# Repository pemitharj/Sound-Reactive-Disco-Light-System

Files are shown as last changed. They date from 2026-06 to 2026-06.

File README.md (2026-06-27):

# Sound Reactive Disco Light System

An analog electronics project that converts real-time audio signals into dynamic LED lighting effects.

---

## Abstract
The Sound Reactive Light System is an analog electronics project designed to produce dynamic lighting effects that respond directly to audio input. The system analyzes different frequency bands of background music and drives LEDs in real time to create interactive visual effects for events and entertainment environments.

---

## Features
- Real-time audio-responsive lighting
- Frequency band separation (Bass, Mid, Treble)
- Analog signal processing (no microcontroller)
- Envelope detection and amplification
- LED visualization based on sound intensity

---

## System Overview
The system captures audio signals, amplifies them, and separates them into three frequency bands using analog filters. Each band is processed independently to drive LED outputs based on signal intensity.

---

## Technologies Used
- Analog Electronics
- Active Filters (Low-pass, Band-pass, High-pass)
- Operational Amplifiers
- PCB Design
- LTspice Simulation
- SolidWorks (Enclosure Design)

---

## Results
The system successfully produces real-time LED responses synchronized with music across bass, mid, and treble frequency ranges.

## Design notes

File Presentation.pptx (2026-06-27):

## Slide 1

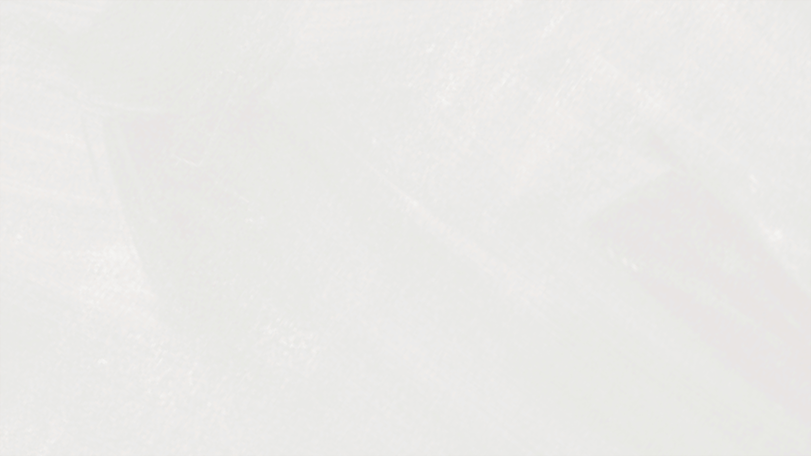
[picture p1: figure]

VoltEdge

SOUND REACTIVE DISCO LIGHT BOX

Samarasekara S.M.R.P. 230564L
Jayakody J.A.C.P. 230268H Kaushalya R.G.S.P. 230327N Jayasinghe J.A.P.R. 230280L

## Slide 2

The Sound Reactive Light System is an analog electronic project designed to create dynamic lighting effects that respond directly to audio signals.
By analyzing different frequency bands of background music, the system drives a set of LEDs to change patterns in real time, enhancing the ambiance and visual appeal at parties or events.
Using analog circuits such as band-pass filters, amplifiers and a regulator, the design processes sound frequencies will cove the concepts in signal processing and circuit design while delivering an engaging interactive experience.

Introduction

3

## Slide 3

1. Sound Capture and Amplification
  - Music is captured via a “Electret Microphone”
  - Preamplification and amplification using “NE5532P , LM358N” OpAmp ICs
  - x11 times amplification

Methodology

3

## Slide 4

2. Frequency band seperation

1. Low Pass Active Filter
  - “NE5532P” OpAmp 2nd order filtering
  - 267Hz cutoff
2.Bandpass
  - “NE5532P” OpAmp 2nd order filtering
  - 328Hz and 2411Hz cutoff
3. Highpass Active Filter
  - “NE5532P” OpAmp 2nd order fltering
  - 3386Hz cutoff

3

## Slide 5

4.Amplification and Driving LEDs

  - All the three bands are amplified and used for LED driving
  - Low Pass by x7.8
  - Bandpass by x11
  - High pass by x11

3

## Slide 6

1. 9V battery will be used as power source
  - LT1086 - 5V model with 10uF capacitances
  - MAX1044 switched capacitor convertor or
a voltage divider circuit.

3.Power Supply

3

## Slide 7

Functionality

MICROPHONE

AMPLIFIER

FREQUENCY FILTERS

LED ARRAYS

LED DRIVE
AMPLIFIER

3

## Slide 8

PCB design

The pcb was created to organize the entire circuit in a clean compact and relaible way.

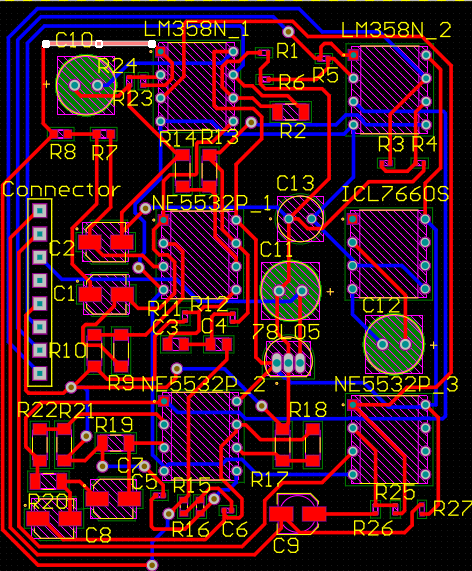
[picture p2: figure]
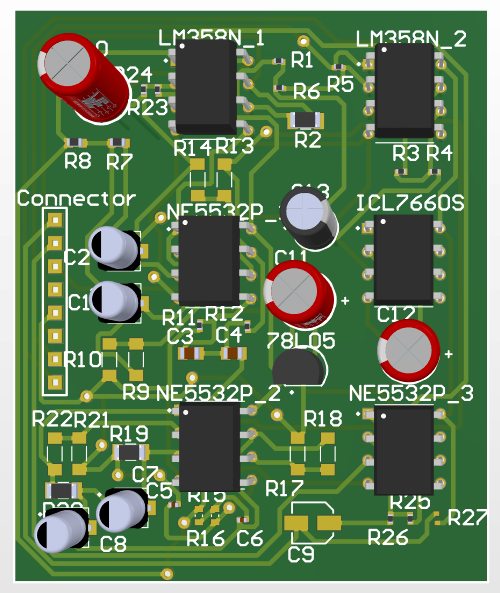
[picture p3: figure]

3

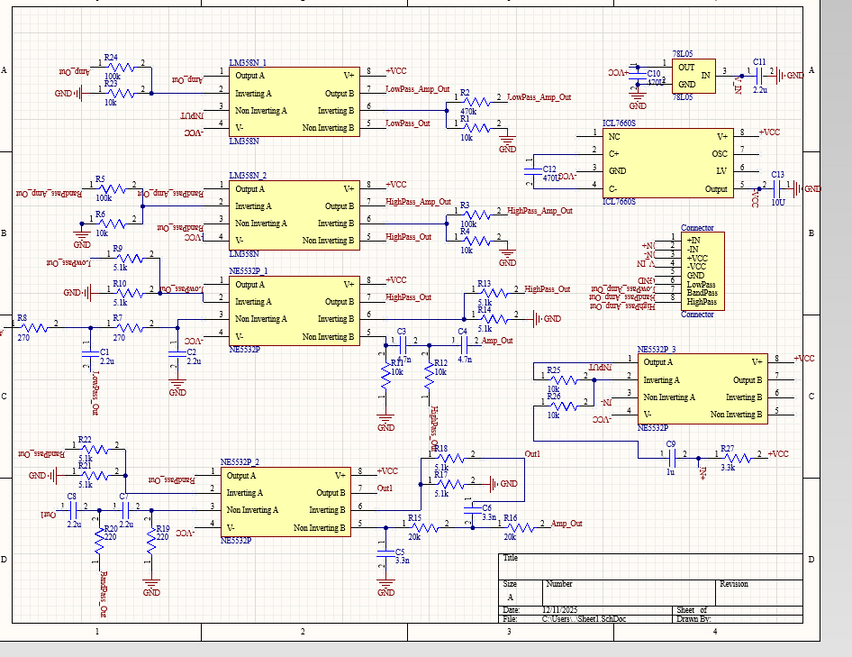
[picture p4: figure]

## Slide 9

PCB design

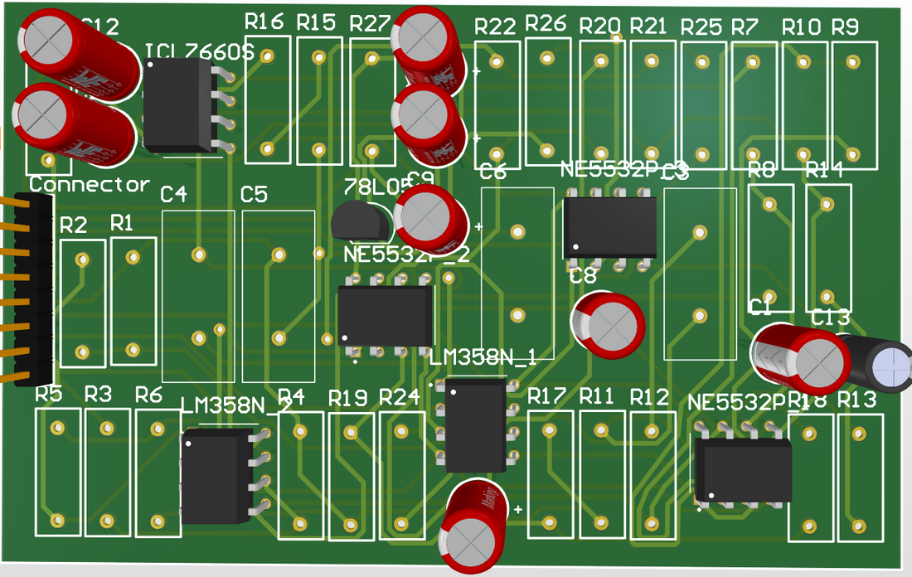
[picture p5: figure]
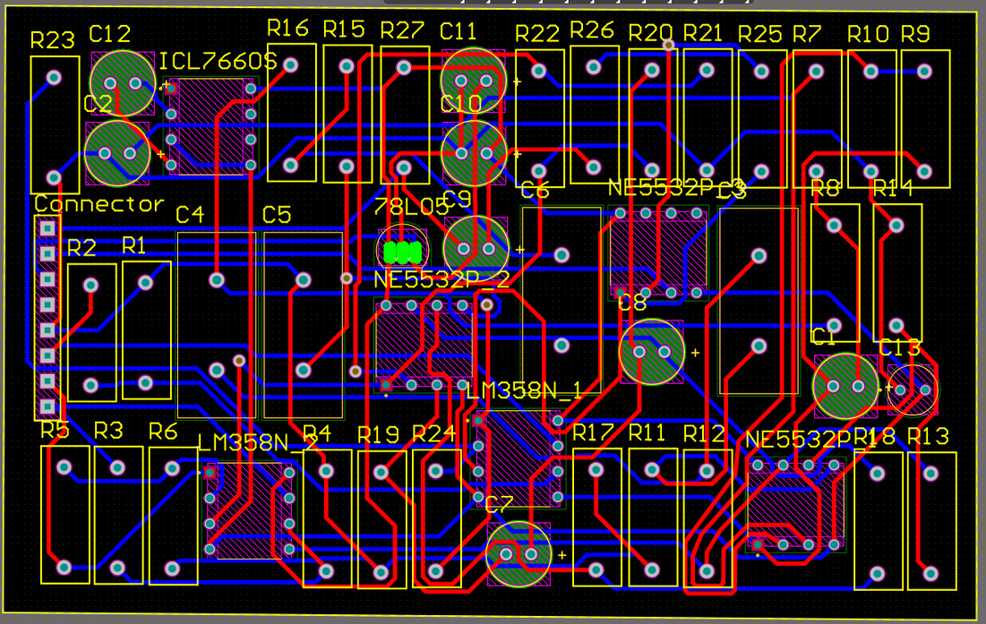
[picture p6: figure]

3

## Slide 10

PCB design

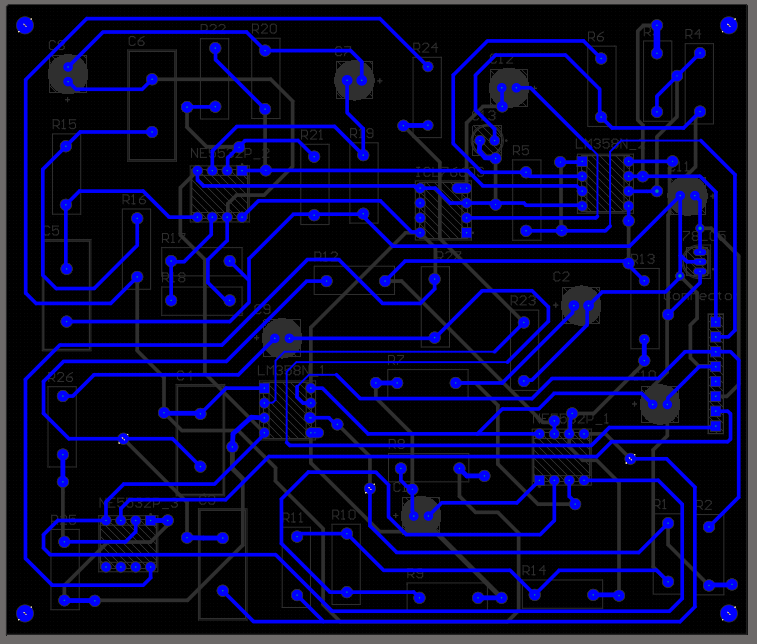
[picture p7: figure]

3

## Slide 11

Enclosure design

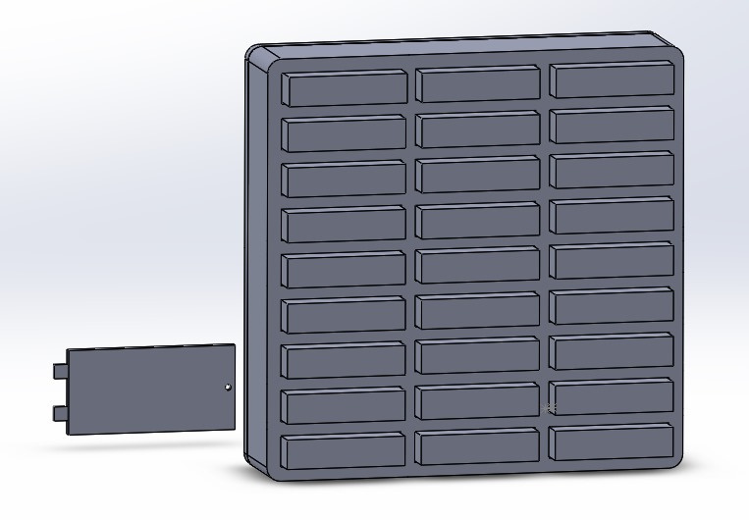
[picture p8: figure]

Enhances the aesthetics of the light box making it suitable for display during events or as part of the room

To protect the circuitry while giving the project a clean, professional appearence.

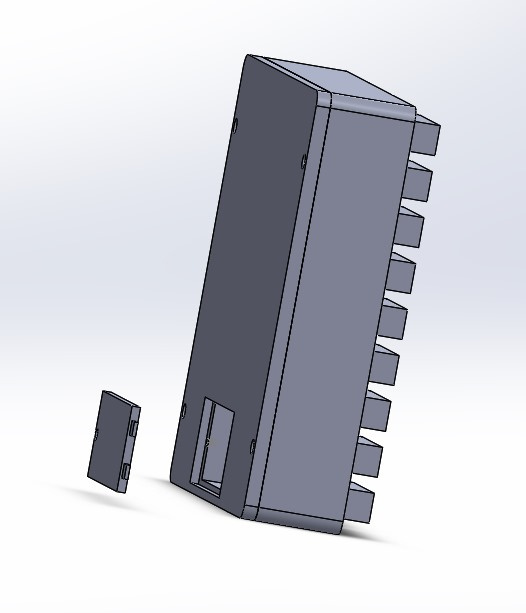
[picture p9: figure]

3

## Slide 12

Task Allocation

3

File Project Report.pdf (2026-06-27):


Department of Electronic & Telecommunication Engineering, University of Moratuwa, Sri Lanka.

# Sound Reactive Disco Light Box

Group Members:

230564L | Samarasekara S.M.R.P.
230268H | Jayakody J.A.C.P.
230327N | Kaushalya R.G.S.P.
230280L | Jayasinghe J.A.P.R

Submitted in partial fulfillment of the requirements for the module EN 2091 Laboratory Practice and Projects

2025.12.06

Sound Reactive Disco Light Box | Group No 29

Abstract

The Sound Reactive Light System is an analog electronics project designed to produce dynamic lighting effects that respond directly to audio input. By analyzing multiple frequency bands of background music, the system drives LEDs to create real-time visual patterns that enhance ambiance at events or parties. The design employs key analog building blocks—including band-pass filters, envelope detectors, and comparators—to isolate and process specific sound frequencies. Through this approach, the project demonstrates essential concepts in signal processing and circuit design while delivering an engaging and interactive audio-visual experience.

1

## Contents

1 Introduction and Functionality | 3
2 System Architecture | 3
3 Component Selection | 4
4 PCB Design | 5
5 Enclosure Design | 6
6 Software Simulation and Hardware Testing | 6
7 Conclusion and Future Works | 8
8 Contribution of Group Memebers | 9
9 References | 9

2

## 1 Introduction and Functionality

The Sound Reactive Light System is an analog electronic project designed to create dynamic lighting effects that respond directly to audio signals. By analyzing different frequency bands of background music, the system drives a set of LEDs to change patterns in real time, enhancing the ambiance and visual appeal at parties or events. Using analog circuits such as low-pass,band-pass,high-pass filters,amplifiers, the design processes sound frequencies will cove the concepts in signal processing and circuit design while delivering an engaging interactive experience.

- System will capture sound and amplify in real time operation continuously.
- The audio signal is split into three main frequency bands: bass, midrange, and treble.
- All the three bands are amplified and used for LED driving.
- LEDs light up or change patterns based on the intensity and presence of sound in their respective frequency bands.

## 2 System Architecture

Functional Block Diagram

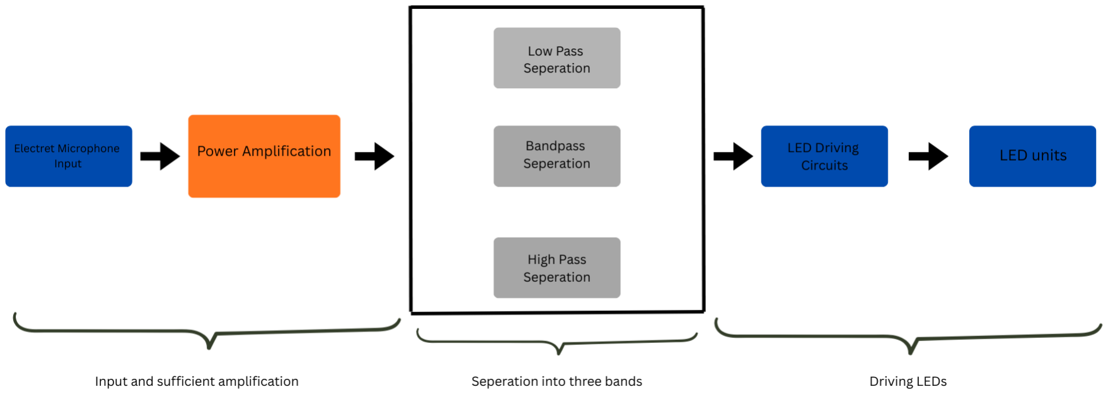
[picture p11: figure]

Figure 1: This is a full-width image.

1. Input
A Electret Condensor Microphoone is use to take the music inputs in to the system. And a DC blocking capcitor of value 1uF in series.
2. Power Amplification
A OpAmp amplification circuit is used to get the enough power amplification to the microphone signal in order to drive the rest of the circuit.
3. Three band seperation
The input audio signal is seperated into three bands of Lowpass, Bandpass and Highpass using Active OpAmp filters.
4. LED switching
Switching LEDs according to the output power of each filters.

3

## 3 Component Selection

### 3.1 Component justification

Component | Functionality | Reason
| Filtering
NE5532P OpAmp | Active filtering | Less distortion
LM358N OpAmp | Converts AC to DC | Less distortion
Power Supply
7805 voltage regulator | To provide +5v +VCC to opamps and LEDs | accuracy of about ±4%
ICL 7660S power invertor | Invert +5V to get -5V -VCC | Improves noise reduction
9V battery | Provide 9V DC power | availability and easy replacement
Input and Amplification
Condernsor microphone | Accepts music input signal | High sensitivity, compact size and low power requirements
NE5532P OpAmp | Amplifies input signal | Low noise of 15nV and less dis-tortion than other tested LM324 and TL072

Table 1: Circuit components categorized by functional sections

### 3.2 Cutoff frequency calculations

1. Low-Pass Filter Cutoff frequency:

f =

1
2πRC

=

1
2π · 270 · 2.2 · 10⁻⁶
= 267Hz
2. High-Pass Filter Cutoff frequency:

f =

1
2πRC

=

1
2π · 10 · 10³ · 4.7 · 10⁻⁹ = 3386Hz
3. Band-Pass Filter
(i) Low cutoff frequency:

f =

1
2πRC

=

1
2π · 220 · 2.2 · 10⁻⁶
328Hz

(ii) High cutoff frequency:

f =

1
2πRC

=

1
2π · 20 · 10³ · 3.3 · 10⁻⁹ = 2411Hz

4

## 4 PCB Design

The printed circuit board (PCB) for the Sound Reactive Light System was designed using Altium Designer, which enabled accurate schematic capture and efficient layout development. Surfacemount device (SMD) components were selected to achieve a compact and space-efficient design while reducing parasitic effects and improving signal integrity. A two-layer PCB was implemented to simplify routing, provide proper grounding, and minimize noise in sensitive analog signal paths. After completing all design rule checks (DRC) and final verification, the PCB was fabricated and assembled through JLCPCB, ensuring reliable manufacturing quality and dimensional accuracy.

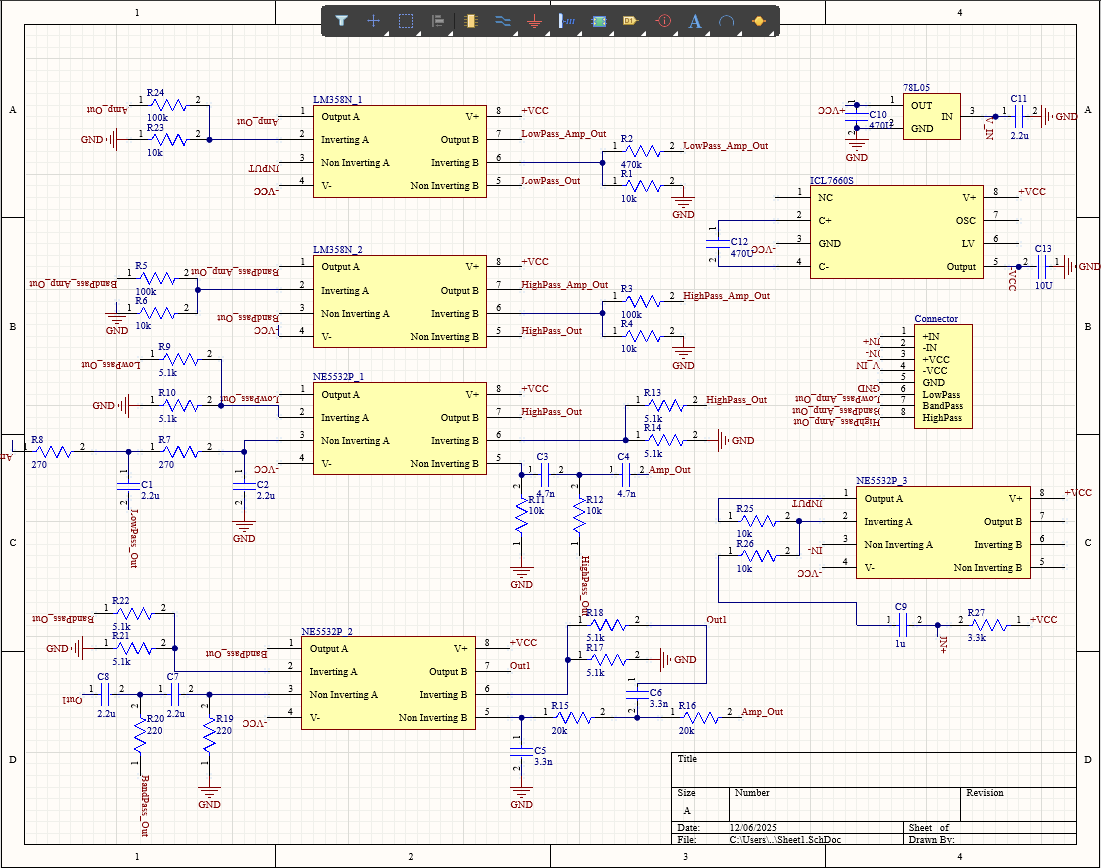
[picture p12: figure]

Figure 2: PCB Schematic

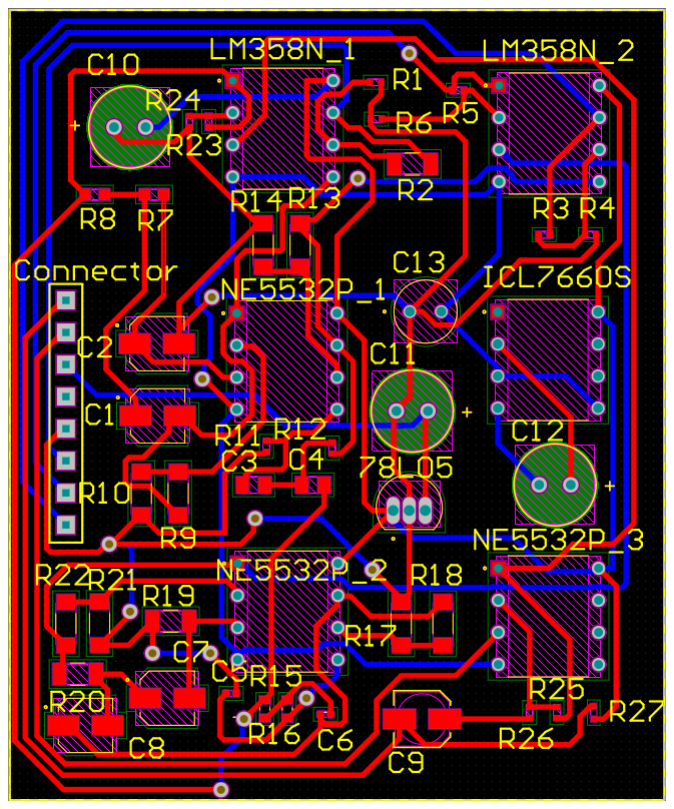
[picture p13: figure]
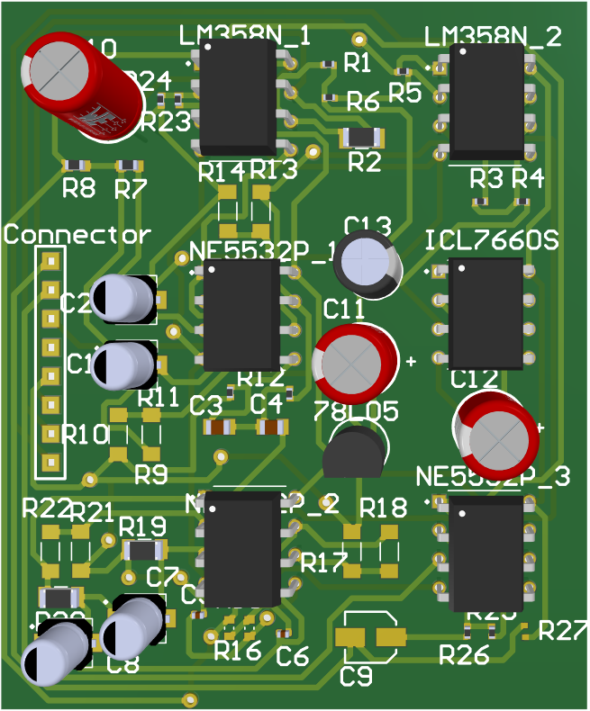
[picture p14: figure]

(a) 3D view PCB | (b) Routine of PCB

5

## 5 Enclosure Design

The enclosure for the Sound Reactive Light System was designed to provide a durable, safe, and visually appealing housing for the electronic circuitry and LED display. Its primary purpose is to protect internal components from physical damage, minimize electrical interference, and enhance the overall user experience by presenting a clean and organized final product.
The enclosure was constructed using PLA (polylactic acid), chosen for its strength, ease of fabrication, and cost-effectiveness. This material also offers good thermal stability and provides an aesthetically pleasing finish suitable for a display-oriented project.
The low thickness used in LED boxes allowed the LED effects to be visible while safeguarding the electronics inside.

Structural Layout
The internal layout was designed to ensure efficient use of space and proper separation of functional blocks. The PCB containing the band-pass filters, envelope detectors, and comparators was mounted securely using standoffs to prevent vibration and short circuits. The LED arrays were positioned along the front panel for maximum visibility, while wiring channels were created to keep signal lines organized and prevent noise coupling. A dedicated compartment was provided for the power supply to minimize interference with sensitive analog circuits.

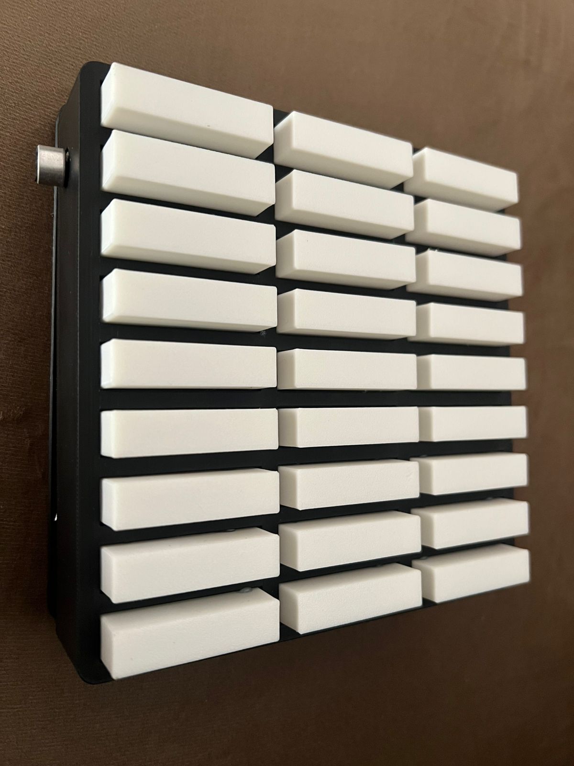
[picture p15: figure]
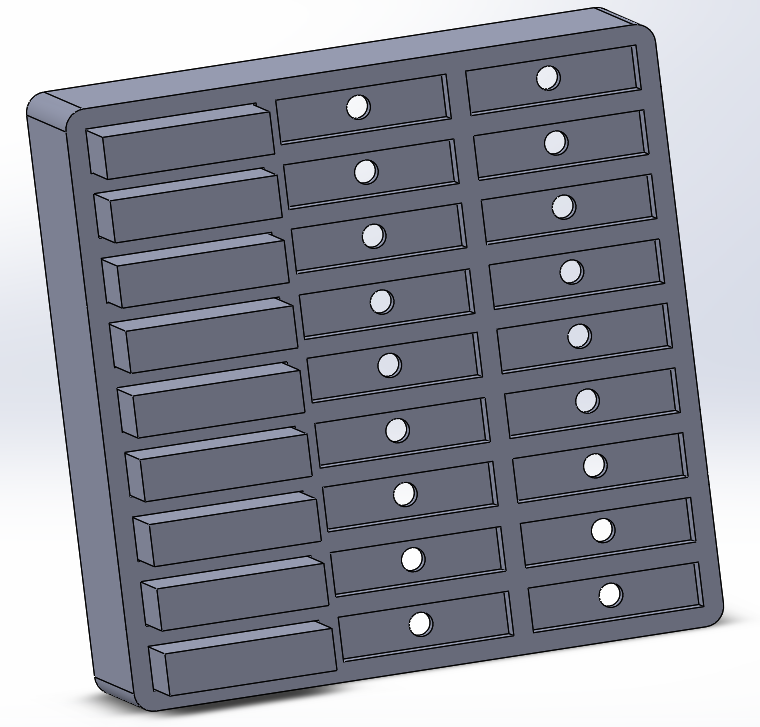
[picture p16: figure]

(a) Designed Enclosure | (b) Enclosure of the product

## 6 Software Simulation and Hardware Testing

The frequency response of the Sound Reactive Light System was simulated using LTspice. Each of the filters—low-pass, band-pass, and high-pass—was modeled with the actual component values chosen for the design. The simulations allowed us to verify that the cutoff frequencies of the filters matched the theoretical calculations, ensuring that each frequency band would correctly trigger its corresponding LED channel. This process provided confidence that the system would perform as expected before hardware implementation.

6

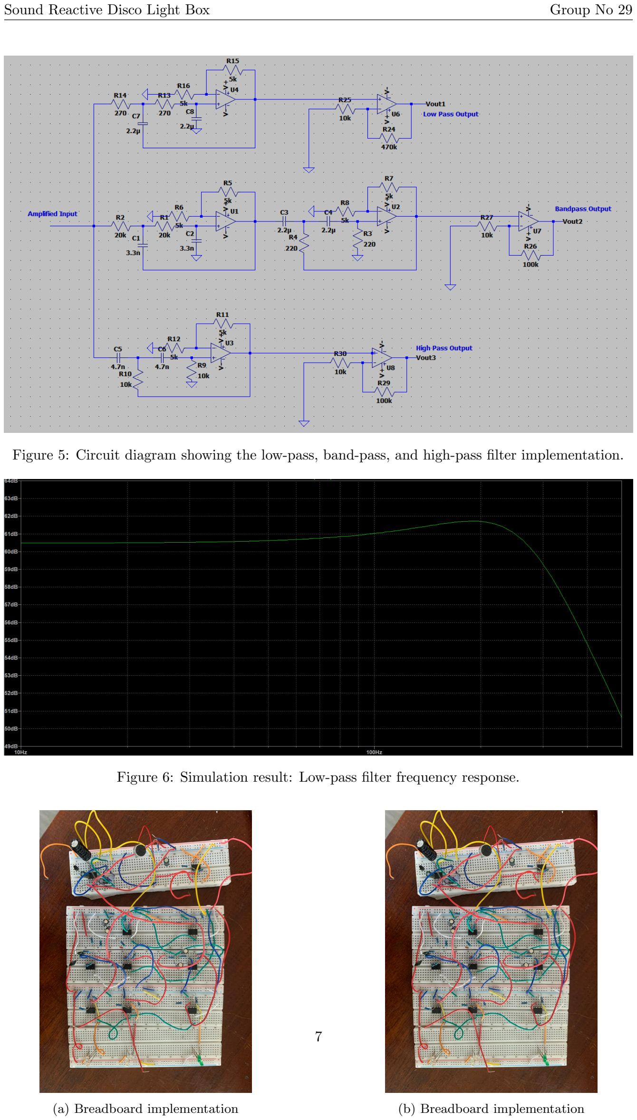
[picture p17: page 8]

Figure 5: Circuit diagram showing the low-pass, band-pass, and high-pass filter implementation.

Figure 6: Simulation result: Low-pass filter frequency response.

(a) Breadboard implementation | (b) Breadboard implementation

7

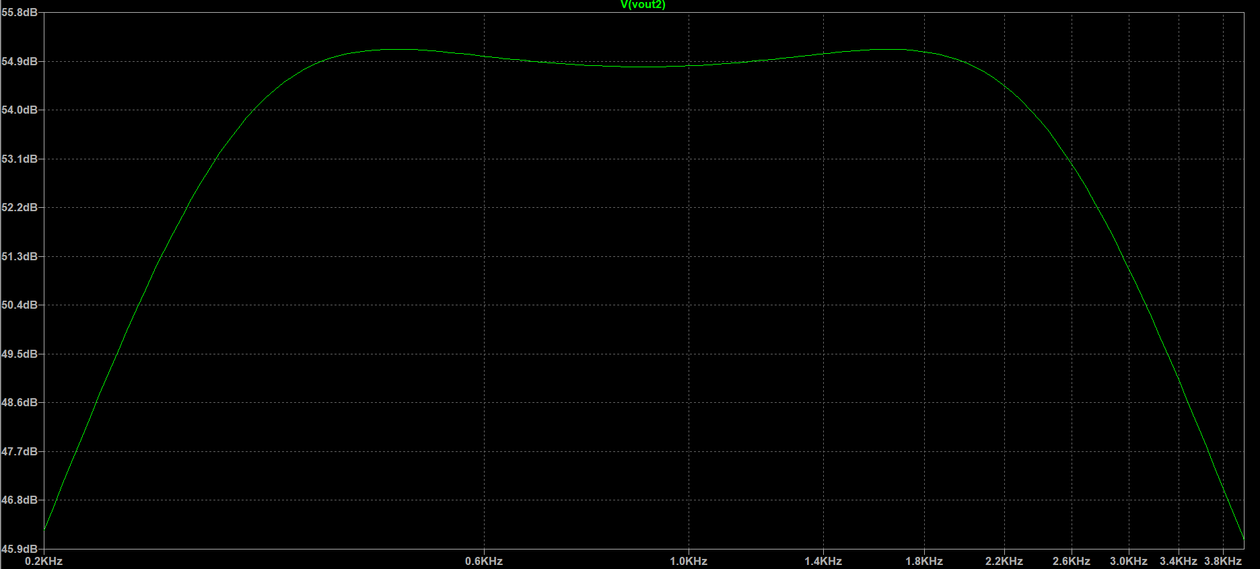
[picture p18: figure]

Figure 7: Simulation result: Band-pass filter frequency response.

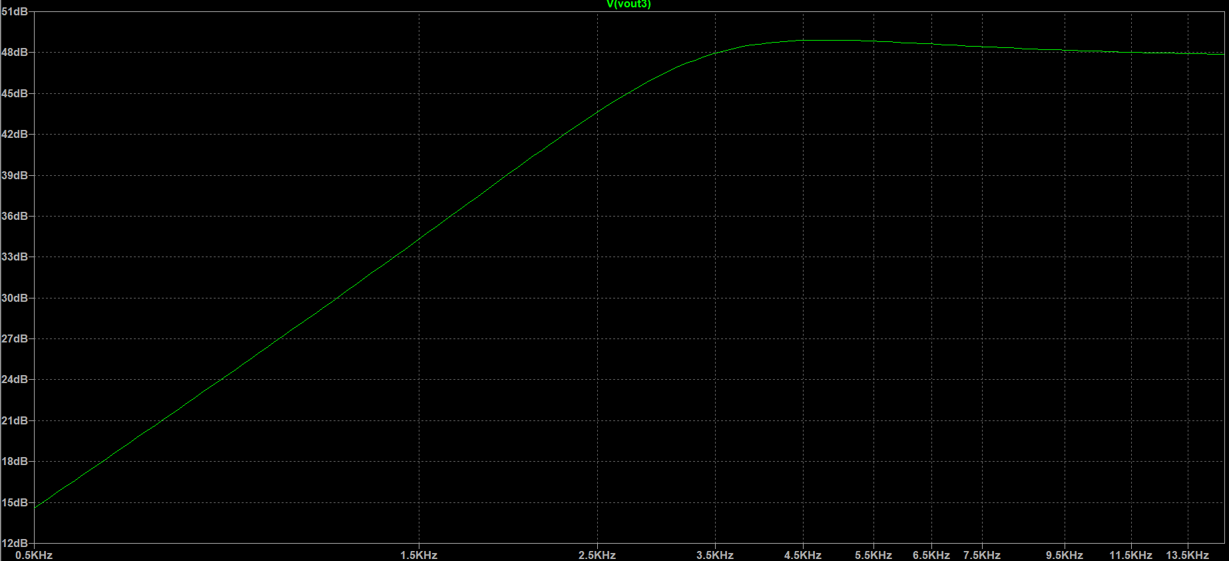
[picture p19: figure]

Figure 8: Simulation result: High-pass filter frequency response.

## 7 Conclusion and Future Works

This project successfully demonstrated the design and implementation of an analog sound-reactive disco light system using only discrete and analog components. Audio signals captured by an electret condenser microphone were amplified, filtered, and processed to control the lighting circuit in response to sound intensity. Hardware testing confirmed stable and reliable operation with effective noise reduction. The compact two-layer PCB designed using Altium with SMD components satisfied all functional requirements and met the project objectives. Future Developments

1. Implemeting a 3.5mm audio jack
-Using a 3.5mm audio port for inputs where user can switch between either microphone input or audio port input. Which enables more flexibity in high noise environmnet.

8

2. Enclosure improvments - Using a adjustbale stand which can adjust the angle of the LED arrays which give a better experience.

## 8 Contribution of Group Memebers

Index | Name | Tasks
230564L | Samarasekara S.M.R.P. | Software simulation and Soldering
230268H | Jayakody J.A.C.P. | Enclosure Design and PCB Design
230280L | Jayasinghe J.A.P.R | Breadboard implementation and PCB Design
230327N | Kaushalya R.G.S.P. | Breadboard implemntation and PCB Design

Table 2: Group members and their assigned tasks

## 9 References

1. The power supply for this project was designed according to the guidelines provided on https://bestengineeringprojects.com/dual-polarity-5v-from-9v-battery/.
2. OpAmp Datasheets https://www.alldatasheet.com/datasheet-pdf/pdf/17968/PHILIPS/NE5532.html,https://www.alldatasheet.com/datasheet-pdf/pdf/11678/ONSEMI/LM358N.html
3. Voltage Regulators https://www.alldatasheet.com/datasheet-pdf/pdf/69437/KEC/7805.html,https://www.alldatasheet.com/datasheet-pdf/pdf/1046626/RENESAS/ICL7660.html

9
